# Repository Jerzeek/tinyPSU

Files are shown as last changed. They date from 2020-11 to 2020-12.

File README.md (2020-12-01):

#  TinyPSU ⚡ 
>Take any USB-C power supply and make it into a high precision, voltage and current control power supply for just 12 euro!
<br>

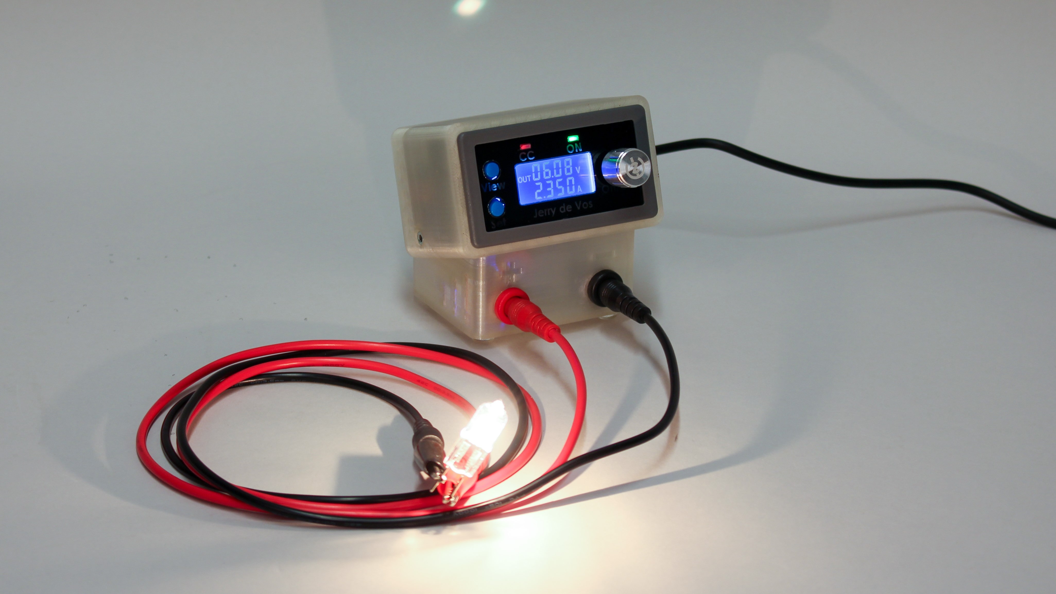
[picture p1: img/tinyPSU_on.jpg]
The tiny psu!


## Features 🎁
- On/off switch
- Reverse connection protection
- Over current protection
- Over power protection
- Over temperature protection
- Timeout protection
- Input and output calibration
- The USB-C chip inside negotiates for the highest voltage afterwhich it can be set anywhere from 0.5-30 volts.

## Video 🎥
A short video about the process:

<a href="http://www.youtube.com/watch?feature=player_embedded&v=lPeCsuVD0Uc
" target="_blank">video</a>

## Background 🧠
This project got started when Brian Lough released [this video](https://youtu.be/Xdq6dzH26QY) He build a simple USB-C Power Delivery bench power supply for just 12 dollar! in the video he shows all the components that you need and how it works (a must see)!

In the video he mentions some improvements of which one was the case design. I headed to the comments and got to work!

After a few designs I settles on a simple two part design that can easily be printed and clicked together.
I made a **BASIC** and **Pro** version
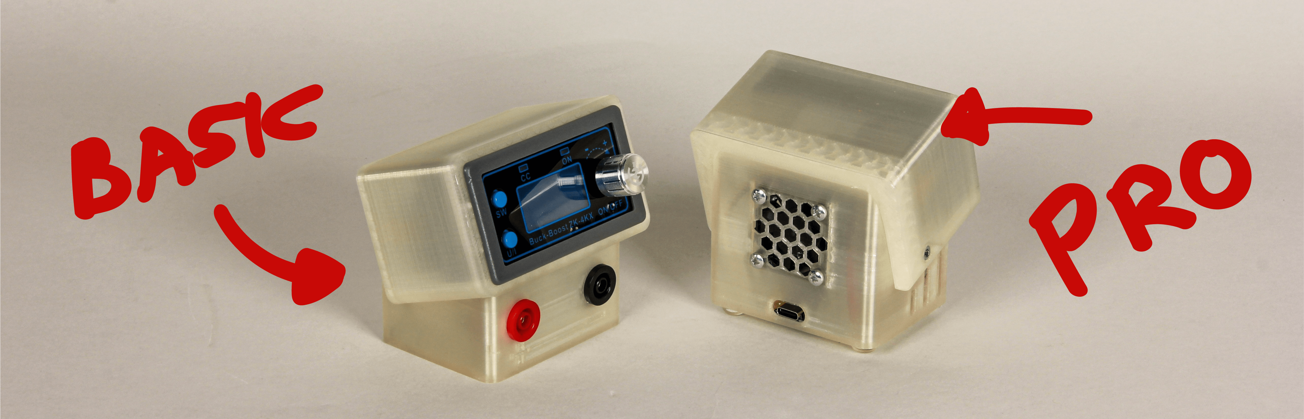
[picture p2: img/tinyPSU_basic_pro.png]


## Basic Version 😺
Basic version houses the same components as in Brian's video.
It takes 6 hour to print, a slight bit or support material needs to be removed and all components can be slit in place and wired.

## Pro Version 🐱‍👤
The Pro version contains the same components as the basic version but is screwed together and adds a fan to keep the module cool.

## Components 💸
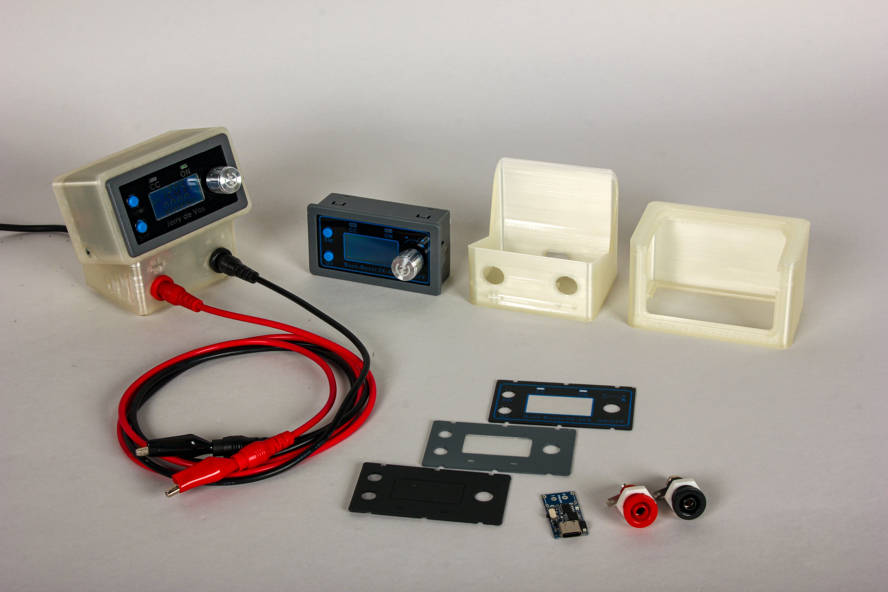
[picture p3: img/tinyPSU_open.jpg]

The components you need for this are the following:

| Component | Price | Link  |
| --- |---:| -----:|
| Variable buck boost converter | €7.61 | [link](https://nl.aliexpress.com/item/4001078401775.html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) |
| PDC005 USB connector | €1.44 | [link](https://nl.aliexpress.com/item/4001253821461.html) |
| Banana socket | €1.28 | [link](https://nl.aliexpress.com/item/4001315056705.html?spm=a2g0s.9042311.0.0.38514c4dVRb7Zd) |
| Fan(only for Pro) | €0.44 | [link](https://nl.aliexpress.com/item/32918866763.html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,searchweb201602_,searchweb201603_) |
| Buck converter for fan (only for Pro) | €0.25 | [link](https://nl.aliexpress.com/item/32725312642.html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,searchweb201602_,searchweb201603_) |
| M3 4mm insert (2x) (only for Pro) | €0.25 | [link]() |
| M3 8mm bolt inbus (2x) (only for Pro) | €0.25 | [link]() |

## 3D models 📐
all the 3D models and files are made in Fusion360 and can be found [here](https://a360.co/3dzU4cF)

I would recommend this print orentation, total print time on the Prusa Mini is about 6,5hour and can be printed with bed plate only support.

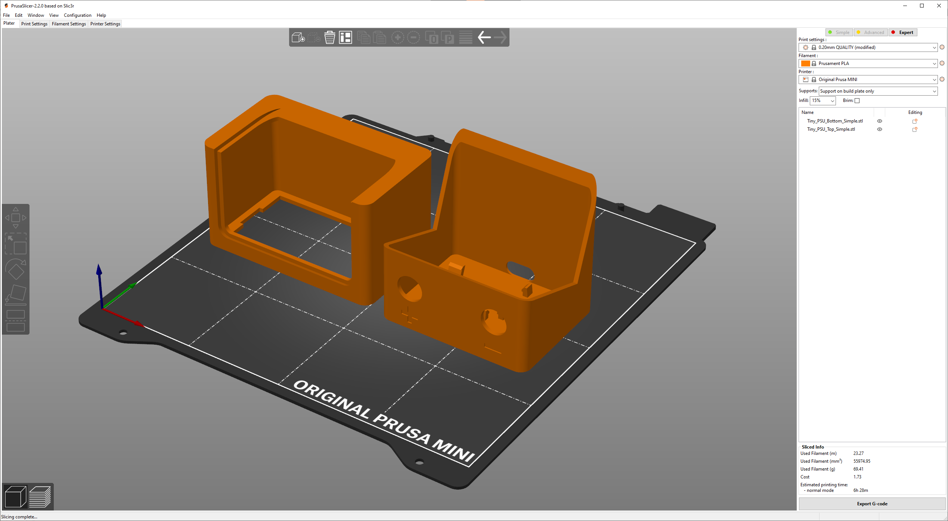
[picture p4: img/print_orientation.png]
Print orientation


## Custom Front! 🧮
Since I was making this model truely mine I wanted to go the extra mile and also finish of front section of the screen
steps to reproduce this:
- lasercut front panel in clear 0.5mm plastic
- mask off sections that need to stay clear
- spray paint the back of the "screen"
- let it dry
- laser engrave away the spray paint.

New Front

Here a picture that shows the custom front.

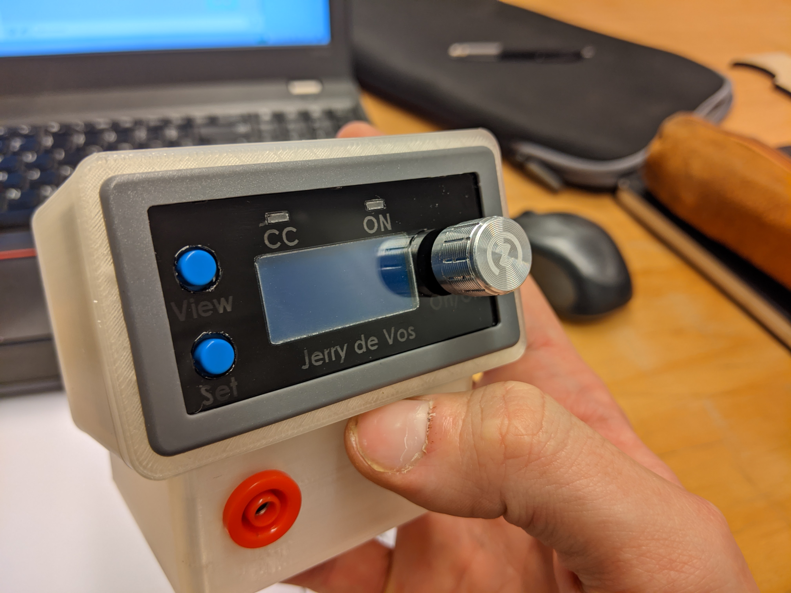
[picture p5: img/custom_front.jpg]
Custom front Custom Front


## Future or To Do 🔮
- [x] Add more pictures to img folder
- [ ] design can be made parametric so its easy to adjust to desired size
- [x] modules seem to be roughly the same front panel size so maybe other models would also fit?

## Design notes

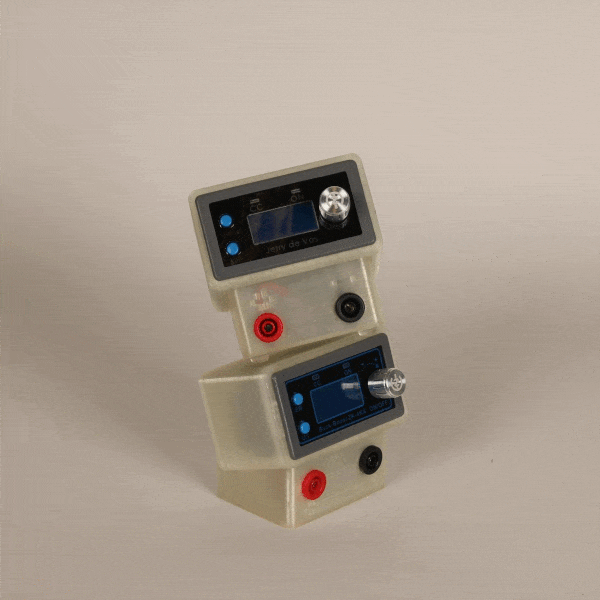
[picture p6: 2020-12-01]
img/tinyPSU_rotating.gif

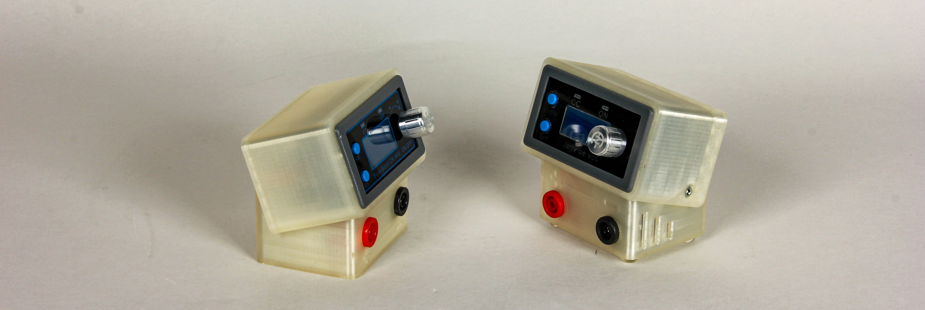
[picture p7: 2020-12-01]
img/tinyPSU.jpg

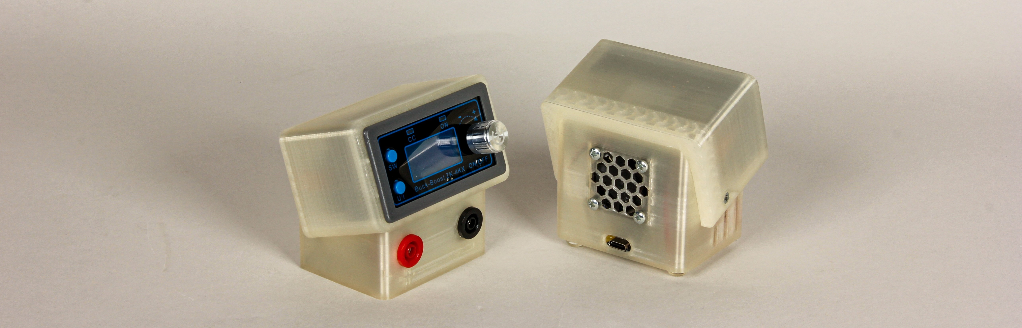
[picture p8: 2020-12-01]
img/tinyPSU_back.jpg

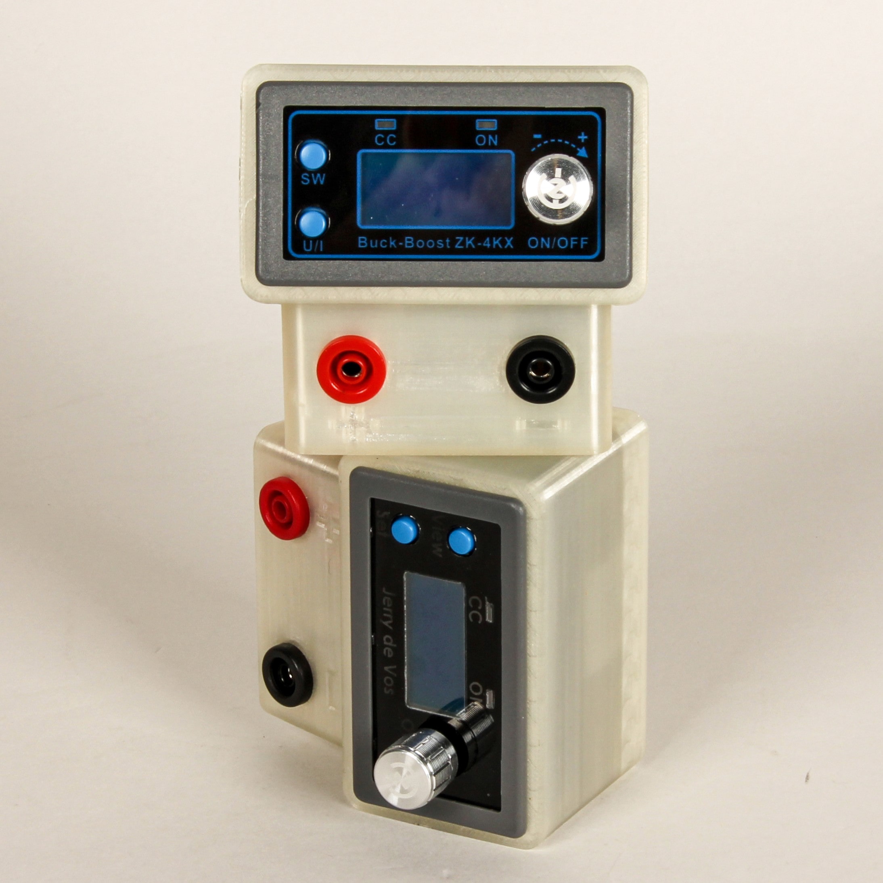
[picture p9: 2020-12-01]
img/tinyPSU_stacked.jpg

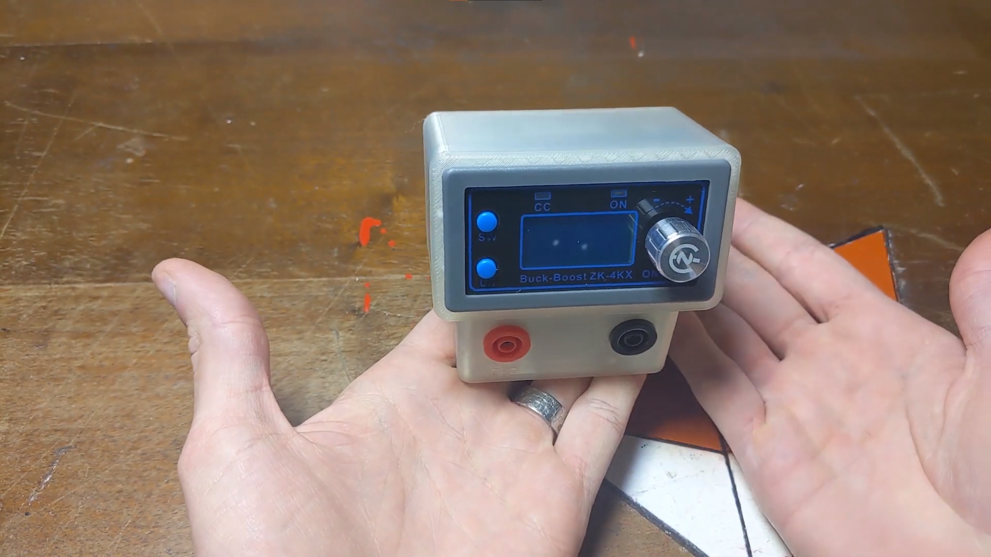
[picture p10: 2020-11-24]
img/tinypsu.png

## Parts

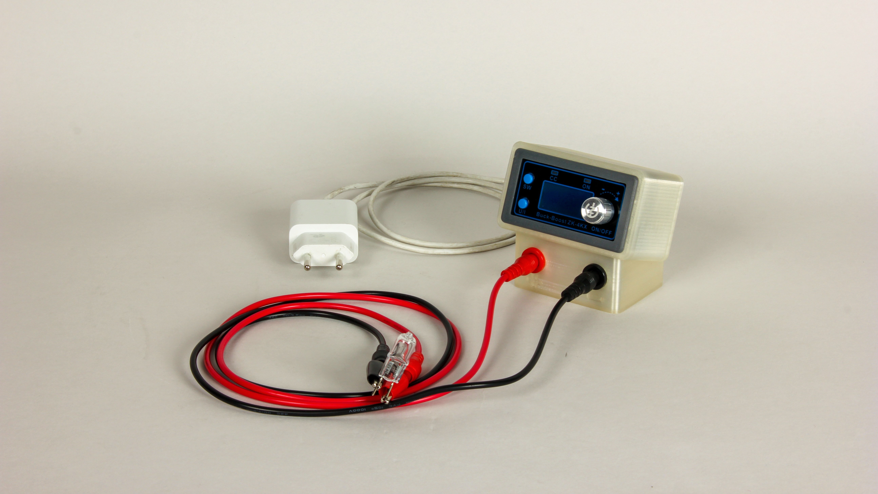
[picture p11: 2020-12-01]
img/tinyPSU_allComponents.jpg

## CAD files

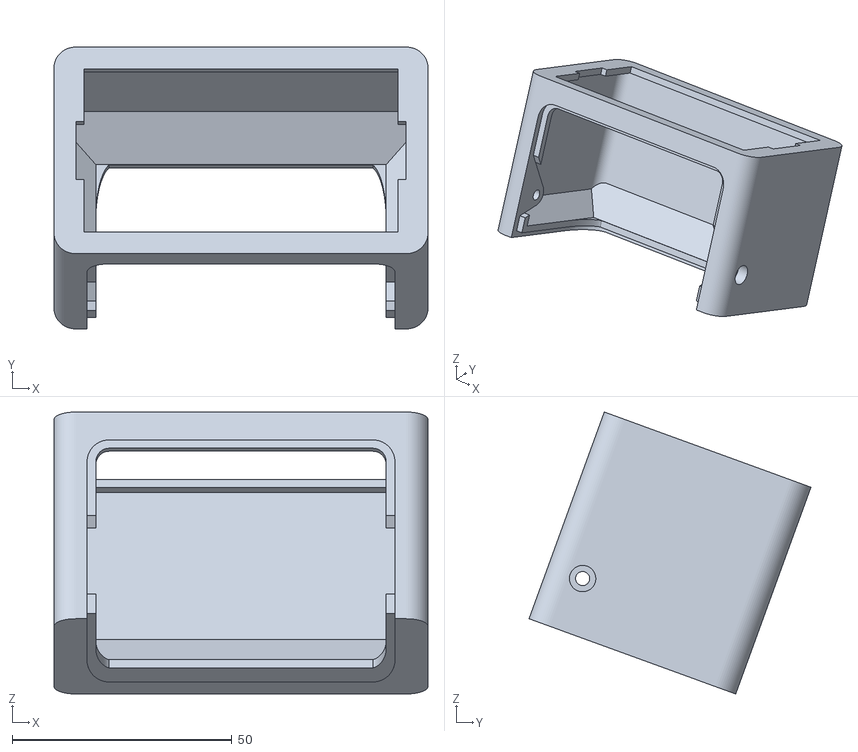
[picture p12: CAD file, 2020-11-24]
3d files/Pro_tinyPSU_top.stl
85.0 x 64.1 x 64.1

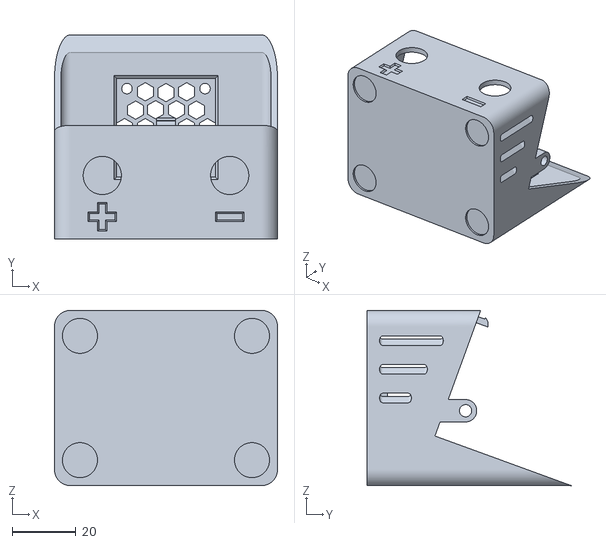
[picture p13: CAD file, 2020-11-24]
3d files/Pro_tinyPSU_bottom.stl
70.0 x 64.1 x 55.0

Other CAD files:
3d files/basic_tinyPSU_bottom.stl
3d files/Basic_tinyPSU_top.stl

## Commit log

2020-11-24 dawn of dayl;ight
    [Tiny_PSU_Bottom_Advanced.stl, Tiny_PSU_Bottom_Simple.stl, Tiny_PSU_Top_Advanced.stl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]
2020-12-01 Added propper pictures📸
    [Basic_tinyPSU_top.stl, Pro_tinyPSU_bottom.stl, Pro_tinyPSU_top.stl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]
